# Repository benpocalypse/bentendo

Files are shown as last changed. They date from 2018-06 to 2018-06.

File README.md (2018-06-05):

# Bentendo DMG
My take on an all in one carrier board for a Raspberry Pi Zero based handheld gaming system. 

## Backstory
I had designed this so that my 4 year old son would have an actual handheld retro system that could be kid friendly. However, after I had designed, layed out, and ordered all the parts, I only found enough free time to partially populate one of them. I hate to see all of my effort go to waste, so I'm putting this out there if anyone else is interested in trying to build one, or to fork my design and improve it.

The design of this board uses a cheap 3.2" screen that runs on the Pi's GPIO pins. I've actually tested this part, and it's working as expected. I designed the controller to use membrane pads like an actual SNES controller (or similar.) The idea was that I would just take one of those cheap SNES USB game pads, and steal the buttons/pads from them, as you can see in the picture below.

The board was designed in KiCAD, and has a BOM in it that can be directly ordered from Digikey. I've also included datasheets for all the important bits in the project as well.

Here is a 3D rendering of the board, made using FreeCAD in combination with KiCAD: 
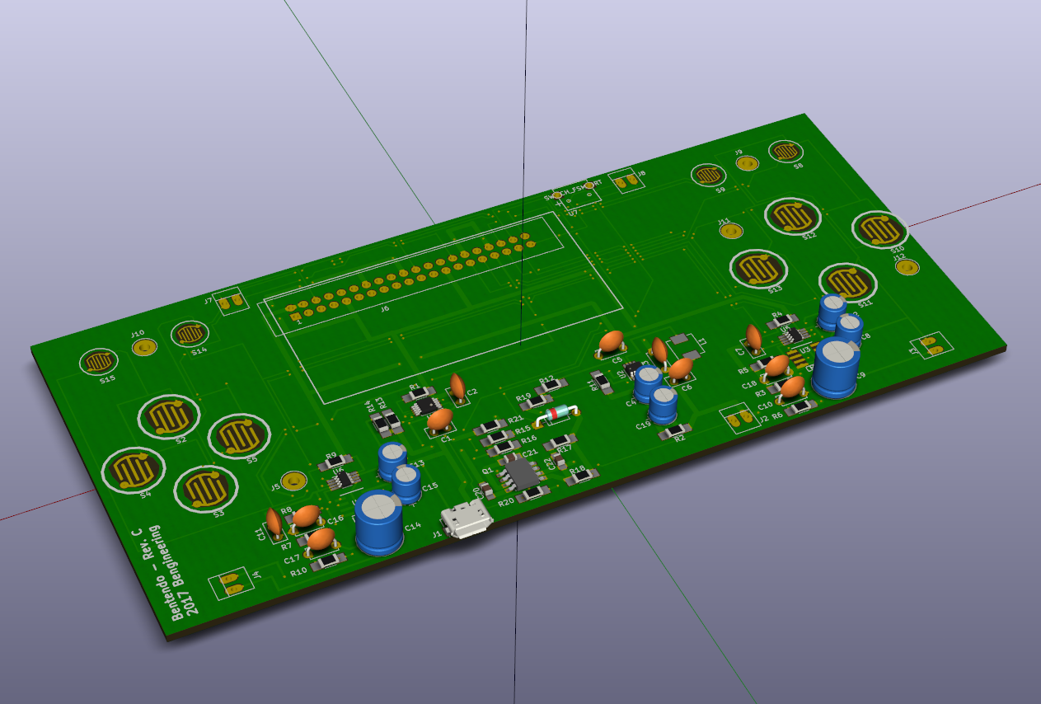
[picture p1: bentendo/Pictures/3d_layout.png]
3D rendering of the board


And here is a picture of the actual board, with some components on it for a dry fit test:
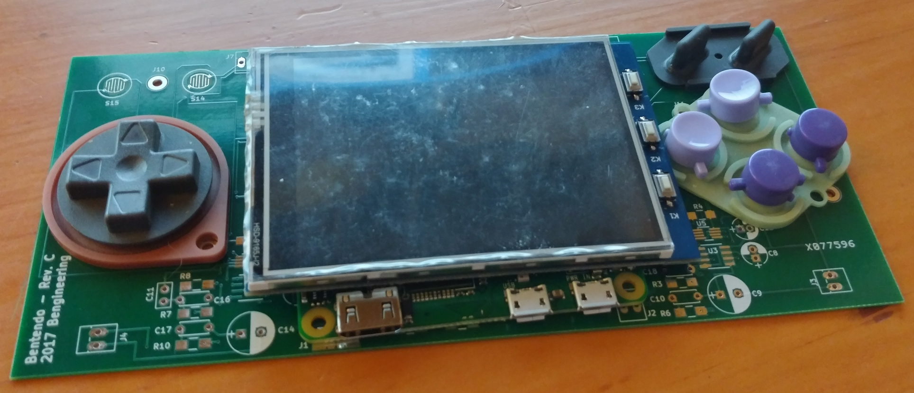
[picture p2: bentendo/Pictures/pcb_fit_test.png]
Acutal board!


And finally, a WIP case design I made in TinkerCAD:
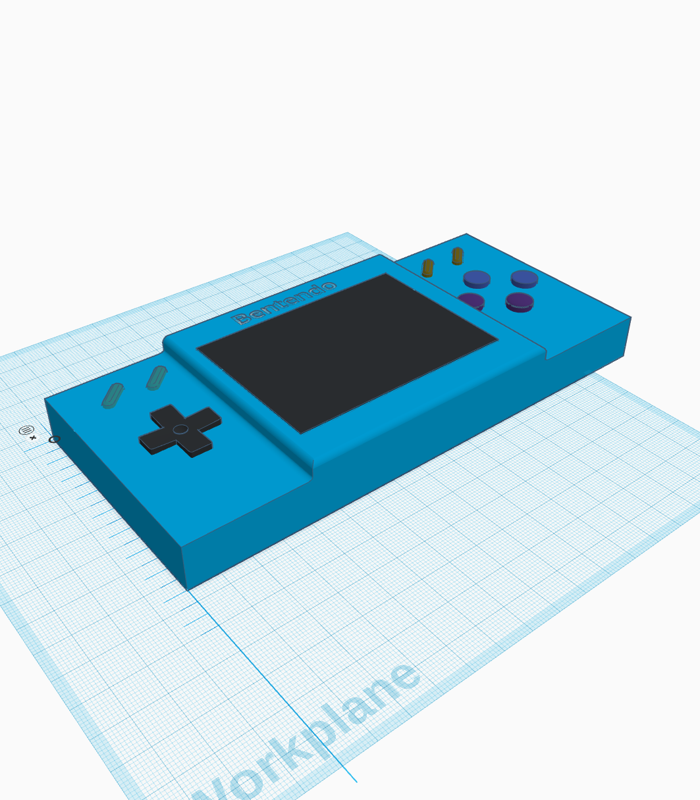
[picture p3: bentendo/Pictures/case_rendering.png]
3D Case WIP


[Here is a link to the WIP case design in Tinkercad if anyone is interested in finishing it.](https://www.tinkercad.com/things/e0lRKZJP2nW-copy-of-bentendo/editv2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)

## The Future
I still plan on coming back to this, but really wanted to put it up on GitHub so that the bits don't get lost to a computer or hard drive failure. I think I'll eventually get some time this fall to build and debug the boards I have. There may be a revision in the future...who knows...

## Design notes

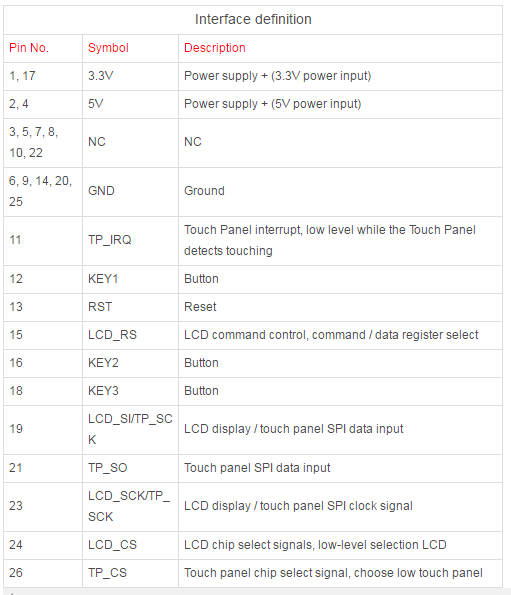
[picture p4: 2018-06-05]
bentendo/Datasheets/3.2 inch screen pinout.png

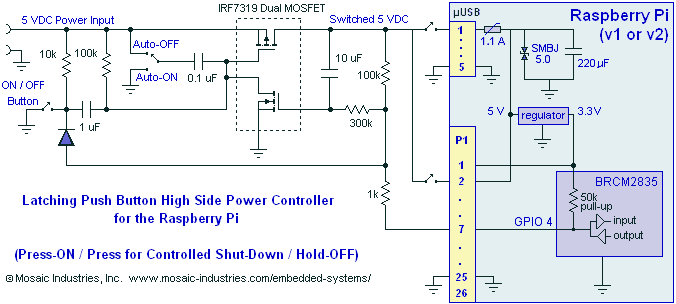
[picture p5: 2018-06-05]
bentendo/Datasheets/shutdown circuit.png

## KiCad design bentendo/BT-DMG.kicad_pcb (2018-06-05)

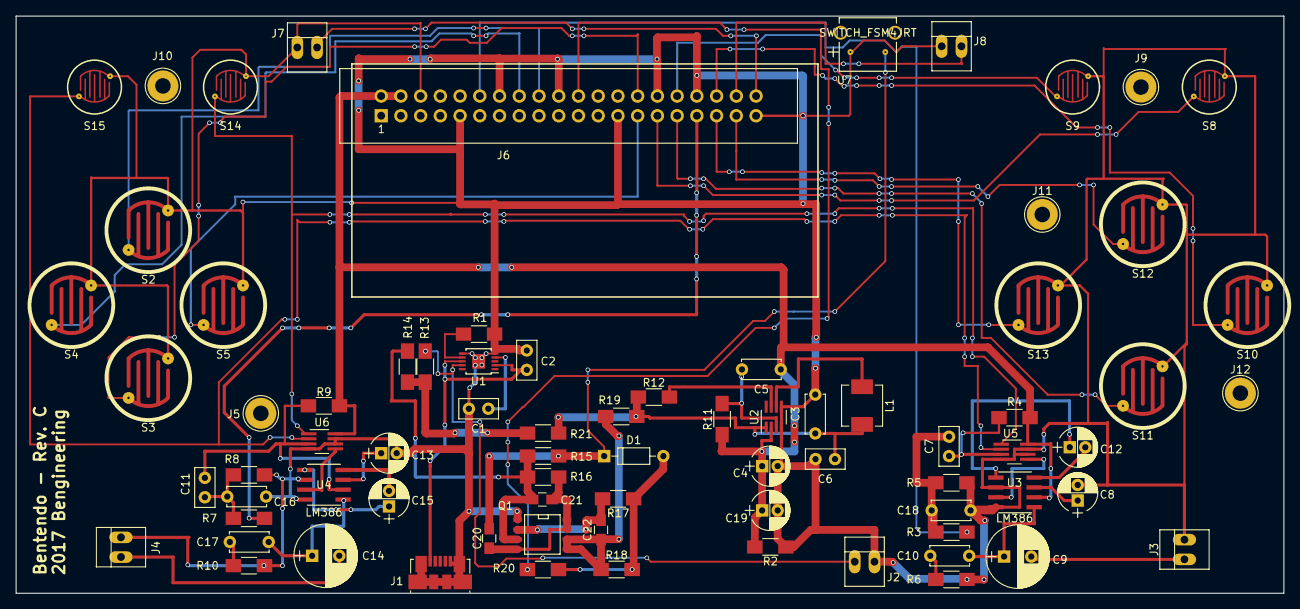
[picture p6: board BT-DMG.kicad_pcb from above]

Board: 2 copper layers, 163.2 x 74.3 mm, 77 parts (0 on the bottom side), 52 nets.

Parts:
C1: 0.47UF; C_Disc_D5.0mm_W2.5mm_P2.50mm
C2: 4.7UF; C_Disc_D5.0mm_W2.5mm_P2.50mm
C3: 1UF; C_Disc_D5.0mm_W2.5mm_P5.00mm
C4, C19: 47UF; CP_Radial_D5.0mm_P2.00mm
C5: 220PF; C_Disc_D5.0mm_W2.5mm_P5.00mm
C6: 22UF; C_Disc_D5.0mm_W2.5mm_P2.50mm
C7, C11: 10UF; C_Disc_D5.0mm_W2.5mm_P2.50mm
C8, C12, C13, C15: 10UF; CP_Radial_D5.0mm_P2.00mm
C9, C14: 220UF; CP_Radial_D8.0mm_P3.50mm
C10, C17: 0.047UF; C_Disc_D5.0mm_W2.5mm_P5.00mm
C16, C18: 33NF; C_Disc_D5.0mm_W2.5mm_P5.00mm
C20: 1uF; C_0805_HandSoldering
C21: 0.1uF; C_0805_HandSoldering
C22: 10uF; C_0805_HandSoldering
D1: D; D_DO-35_SOD27_P7.62mm_Horizontal
J1: USB_OTG; USB_Micro-B_Molex_47346-0001
J2, J3, J4, J7, J8: CONN_01X02; PINHEAD1-2
J5, J9, J10, J11, J12: Conn_01x01; 1pin
J6: Raspberry_Pi_2_3; IDC_Header_Straight_40pins
L1: 1.5UH; L_Vishay_IHLP-2020
Q1: DUAL_MOSFET; SOIC-8-N
R1: 1.5K 1%; R_1206_HandSoldering
R2: 4.99K; R_1206_HandSoldering
R3, R7: 270R; R_1206_HandSoldering
R4, R6, R9, R10, R15: 10K; R_1206_HandSoldering
R5, R8: 127R; R_1206_HandSoldering
R11: 45.3K; R_1206_HandSoldering
R12, R13, R14, R19, R21: 0; R_1206_HandSoldering
R16, R18: 100K; R_1206_HandSoldering
R17: 300K; R_1206_HandSoldering
R20: 1K; R_1206_HandSoldering
S2, S3, S4, S5, S10, S11, S12, S13: MEMBRANE_PAD; membrane_button_small
S8, S9, S14, S15: MEMBRANE_PAD; membrane_button_tiny
U1: LTC4064; MSOP-10-1EP_3x3mm_Pitch0.5mm
U2: RT4812; SOT-23-8_Handsoldering
U3, U4: LM386; LM386MX-1&slash_NOPB
U5, U6: AD5228; TSOT-23-8_HandSoldering
U7: SWITCH_FSM4JRT; 1825027-5

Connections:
+BATT: R13.1, R14.1, R21.2
/5V_CHG: C2.1, J1.1, U1.2, U1.8
/BTN_A: J6.36, S10.2
/BTN_B: J6.31, S11.2
/BTN_X: J6.37, S12.2
/BTN_Y: J6.35, S13.2
/CHL_A: C7.1, R4.2, U5.3
/CHL_W: U3.3, U5.5
/CHR_A: C11.1, R9.2, U4.6, U6.3
/CHR_W: U4.3, U6.5
/D_DOWN: J6.28, S3.2
/D_LEFT: J6.16, S4.2
/D_RIGHT: J6.27, S5.2
/D_UP: J6.18, S2.2
/PWM0: J6.12, R3.2
/PWM1: J6.33, R7.2
/SDOWN: J6.22, R20.1
/SELECT: J6.29, S8.2
/SHLD_L: J6.40, J7.2
/SHLD_R: J6.38, J8.2
/START: J6.32, S9.2
/VOL_DN: S15.2, U5.2, U6.2
/VOL_UP: S14.2, U5.1, U6.1
GND: C1.2, C2.2, C3.2, C4.2, C6.2, C8.2, C13.2, C16.2, C18.2, C19.2, J1.5, J1.6, J2.2, J3.2, J4.2, J6.6, J6.9, J6.14, J6.20, J6.25, J6.30, J6.34, J6.39, J7.1, J8.1, Q1.1, R1.2, R2.1, R5.2, R6.2, R8.2, R10.2, S2.1, S3.1, S4.1, S5.1, S8.1, S9.1, S10.1, S11.1, S12.1, S13.1, S14.1, S15.1, U1.5, U1.6, U1.11, U2.4, U2.5, U3.2, U3.4, U4.2, U4.4, U5.4, U5.6, U5.7, U6.4, U6.6, U6.7, U7.1
unnamed: C1.1, U1.4
unnamed: C3.1, C6.1, L1.2, R12.1, R19.2, R21.1, U2.1
unnamed: C5.2, R11.2, U2.3
unnamed: C8.1, U3.7
unnamed: C9.2, J3.1
unnamed: C9.1, C10.1, U3.5
unnamed: C10.2, R6.1
unnamed: C11.2, C16.1, R7.1, R8.1
unnamed: C12.1, U3.1
unnamed: C12.2, U3.8
unnamed: C13.1, U4.7
unnamed: C14.1, C17.1, U4.5
unnamed: C14.2, J4.1
unnamed: C15.1, U4.1
unnamed: C15.2, U4.8
unnamed: C17.2, R10.1
unnamed: C7.2, C18.1, R3.1, R5.1
unnamed: C20.1, D1.1, R15.2, U7.2
unnamed: C20.2, C21.2, Q1.4, Q1.7, Q1.8, R16.2
unnamed: C21.1, Q1.3, R14.2, R15.1, R16.1
unnamed: C22.1, Q1.5, Q1.6, R18.1, R19.1
unnamed: C22.2, Q1.2, R17.2
unnamed: D1.2, R17.1, R18.2, R20.2
unnamed: J2.1, R13.2, U1.9
unnamed: L1.1, U2.6
unnamed: R1.1, U1.7
unnamed: R12.2, U2.7
VPP: C4.1, C5.1, C19.1, J6.2, J6.4, R2.2, R4.1, R9.1, R11.1, U2.2, U3.6, U5.8, U6.8
